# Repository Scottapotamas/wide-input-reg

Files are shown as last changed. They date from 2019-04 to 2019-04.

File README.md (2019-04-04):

# Wide input (HV) DC Step-down Regulator
This is a smaller board that follows the successful design used on the zaphod-bot delta robot, which used 75VDC input and 12V output, tested at 4A load with 96% efficiency.

This board is intended as a medium scale (~50-100W) standalone version for use with 12S lipo systems (48Vish) and similar high voltage supplies, as its hard to get a high input voltage regulator from Pololu etc.

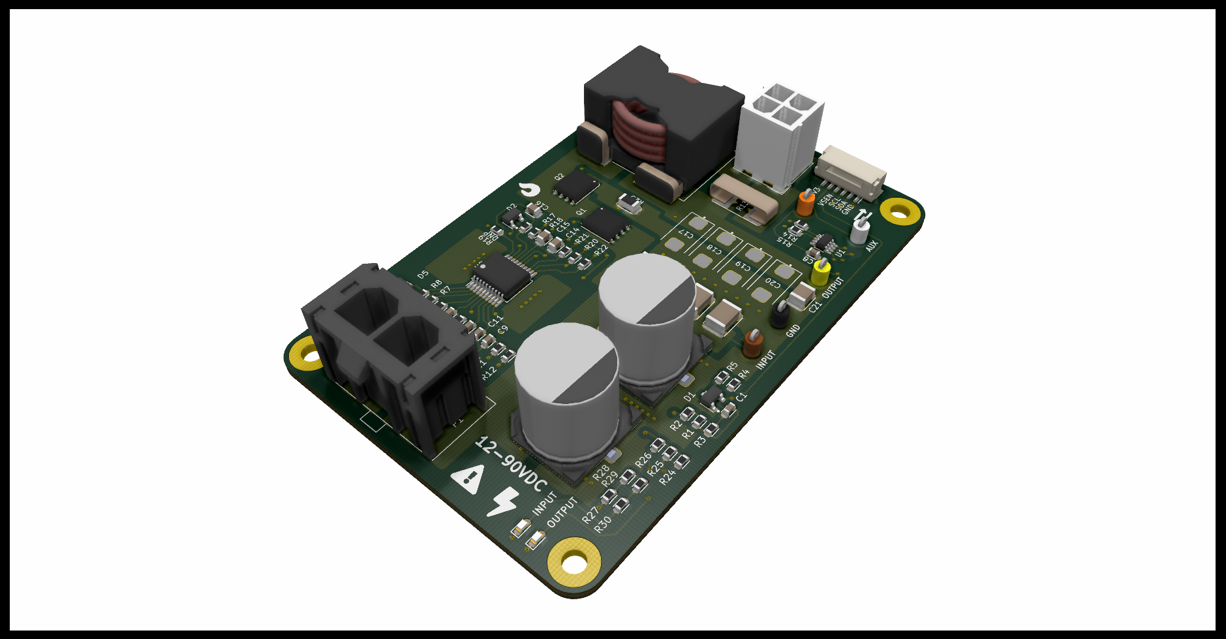
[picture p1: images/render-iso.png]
isometric render view of pcb


## Design Notes

### Regulator

Uses a TI regulator, and a reasonably chunky inductor/filtering stage to ensure stability and efficiency. This design isn't designed for low cost, as I don't forsee low runs, and high voltage systems which require a board like this aren't typically cheap to begin with.

While the regulator and most parts are capable of 100VDC inputs, I've intended the maximum input voltage to be around 80VDC, and I'd expect the design to be used for 5, 12, or 24V outputs (though other outputs are achievable with some component changes).

### Sensing and feedback

Onboard output voltage and current sensing is achieved with the INA219 I2C sense IC, which allows the output voltage and current to be accurately reported to a host microcontroller.

Regulator provides some minimal status indication with 2 leds mounted near the input connector: 

- Red LED indicates the presence of input voltage, and the 

- Green LED indicates the presence of an output voltage. 

- These LED's are 'dumb' and do not indicate if the input/output voltages are _correct_.

A series of onboard solder link jumpers are used to set the I2C address of the INA219, for systems which use multiple regulator boards for different logic levels.

### Connectors

- Input power connection with Molex Sabre 2-pin connector, output with Molex Minifit 4-pin. 

- Data is a JST-GH locking 6-pin connector, which should provide 3.3V, and I2C from the host system. 
  - An (optionally connected) 3.3V analog signal provides input voltage sensing for an ADC, with a 27:1 divider.
  
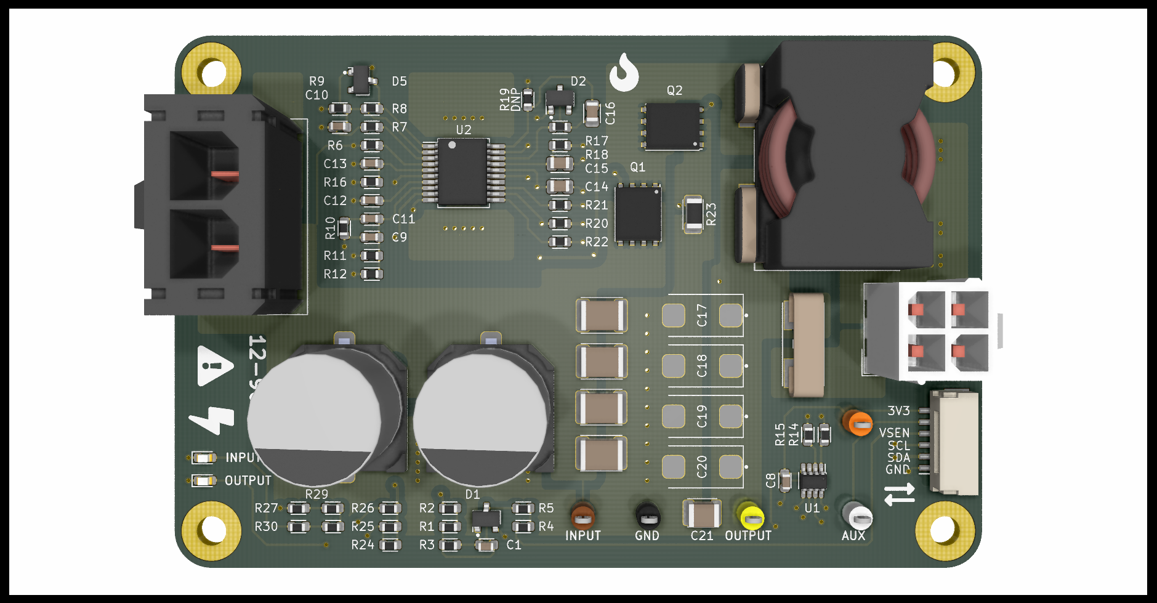
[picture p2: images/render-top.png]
top render view of pcb


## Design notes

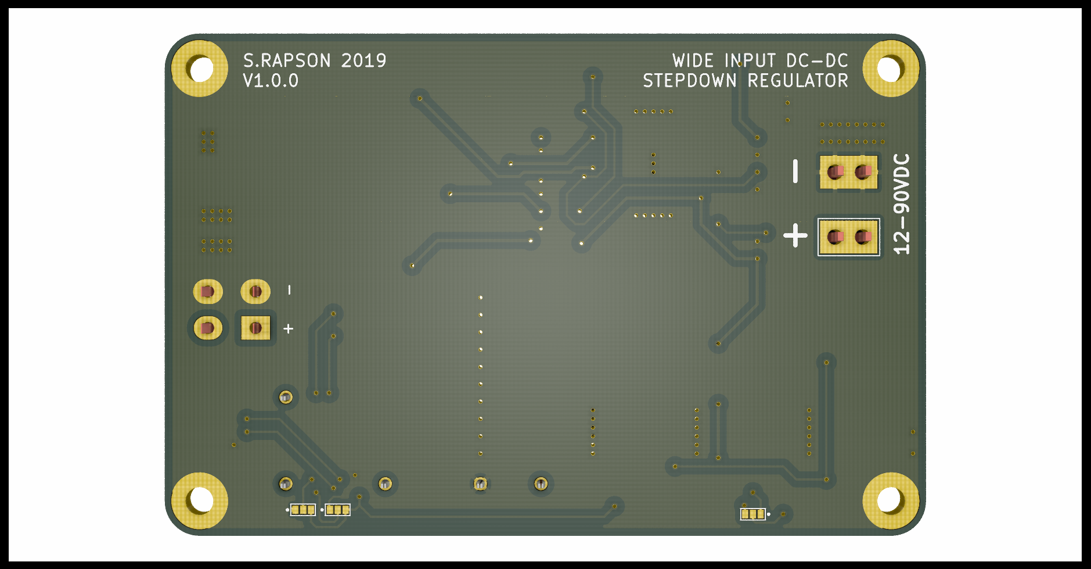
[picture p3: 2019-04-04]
images/render-bottom.png

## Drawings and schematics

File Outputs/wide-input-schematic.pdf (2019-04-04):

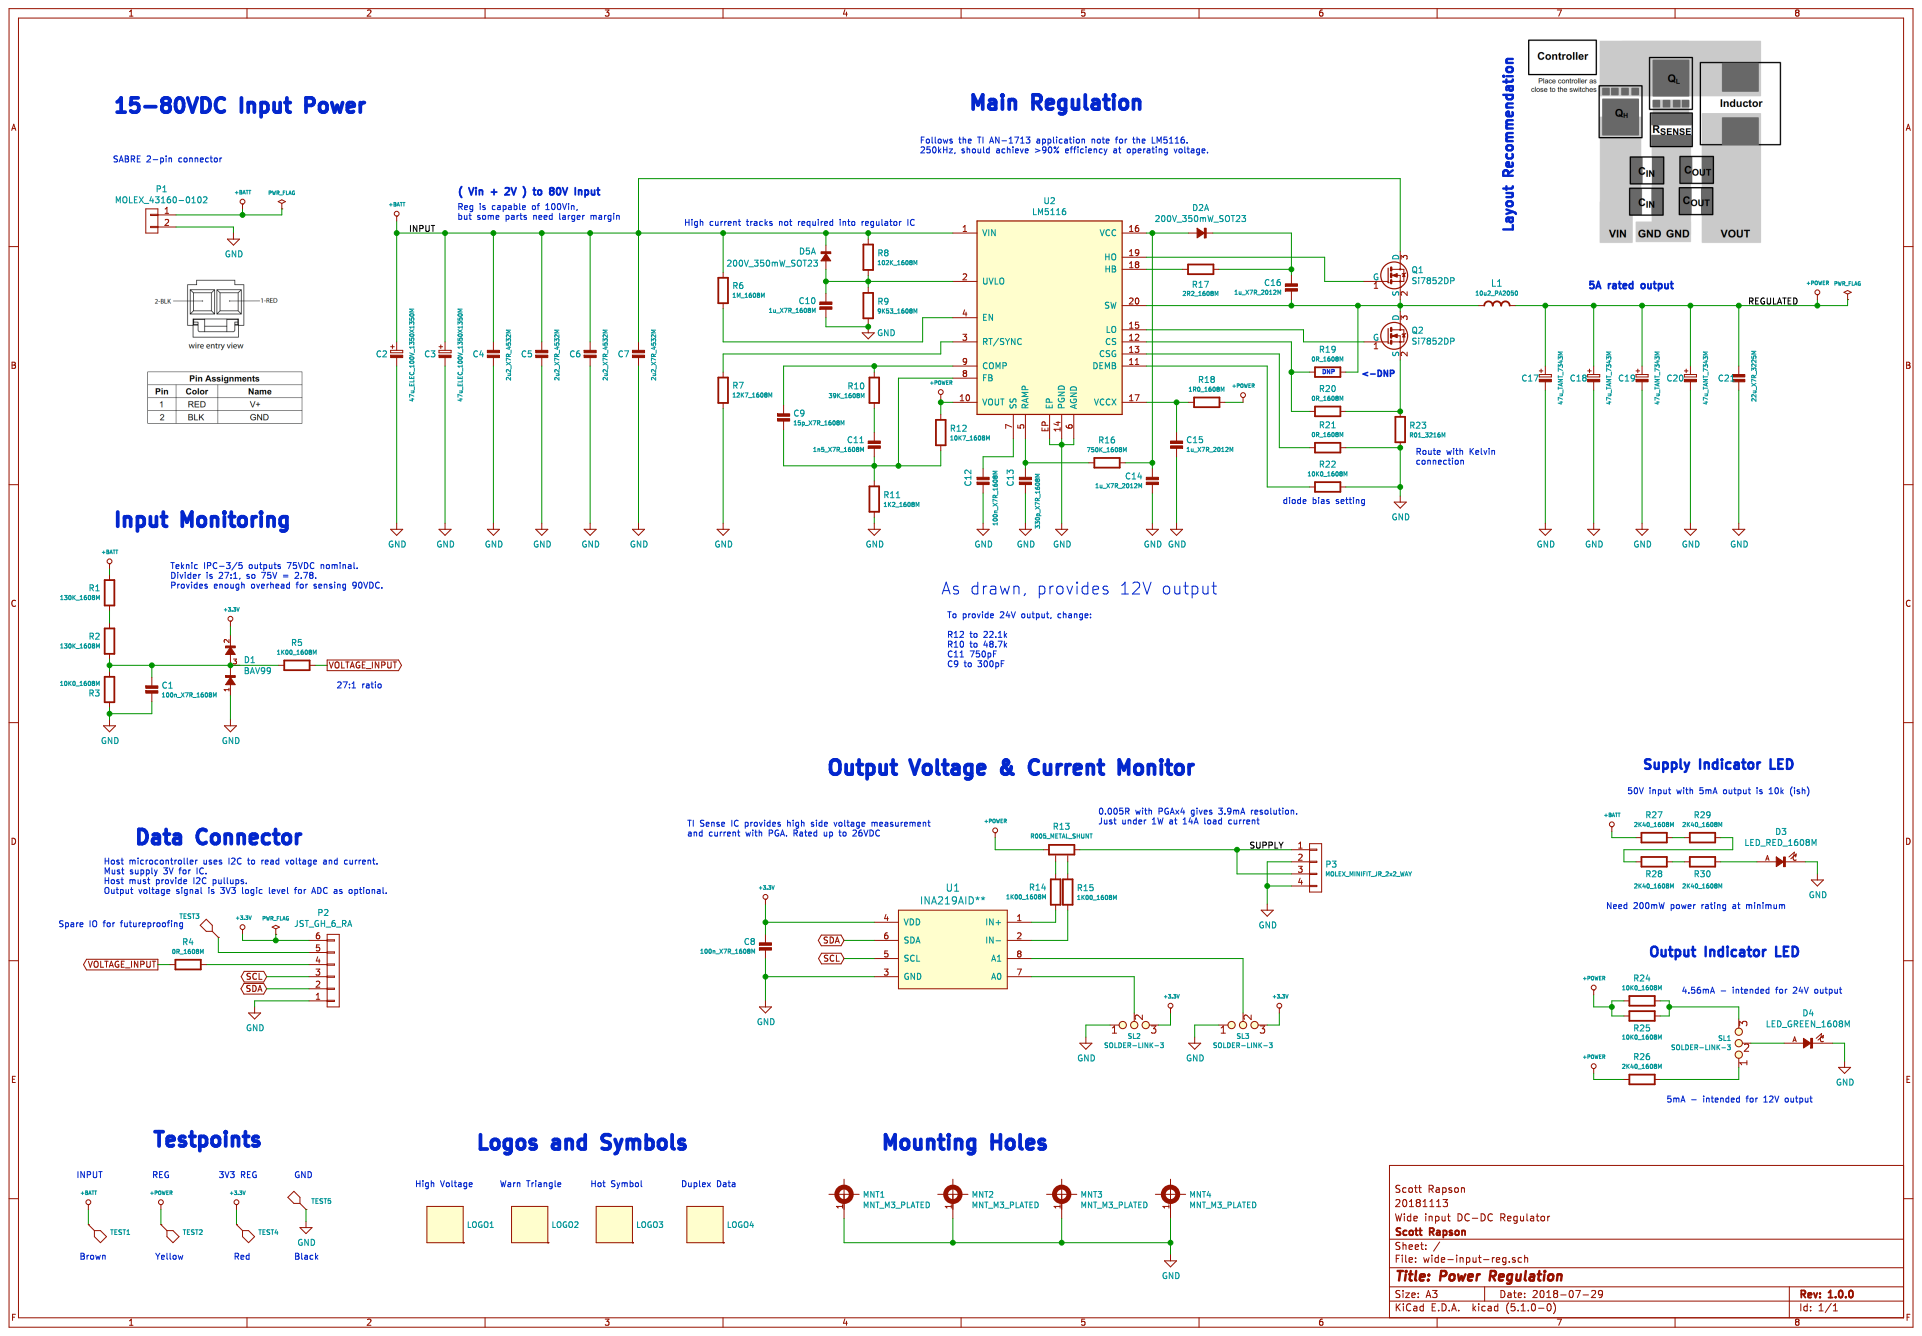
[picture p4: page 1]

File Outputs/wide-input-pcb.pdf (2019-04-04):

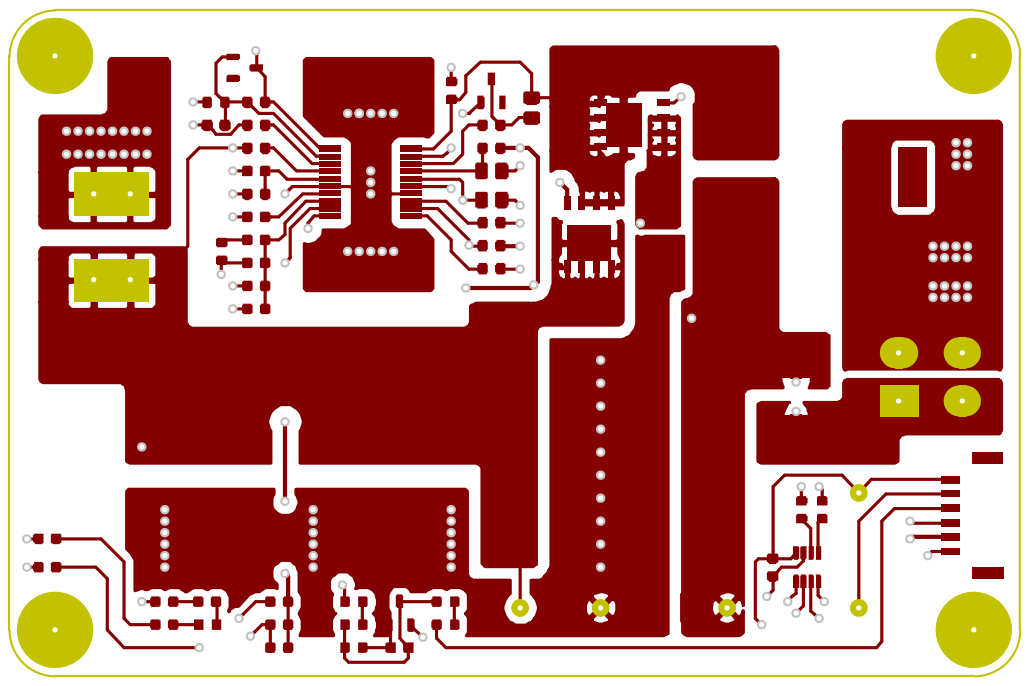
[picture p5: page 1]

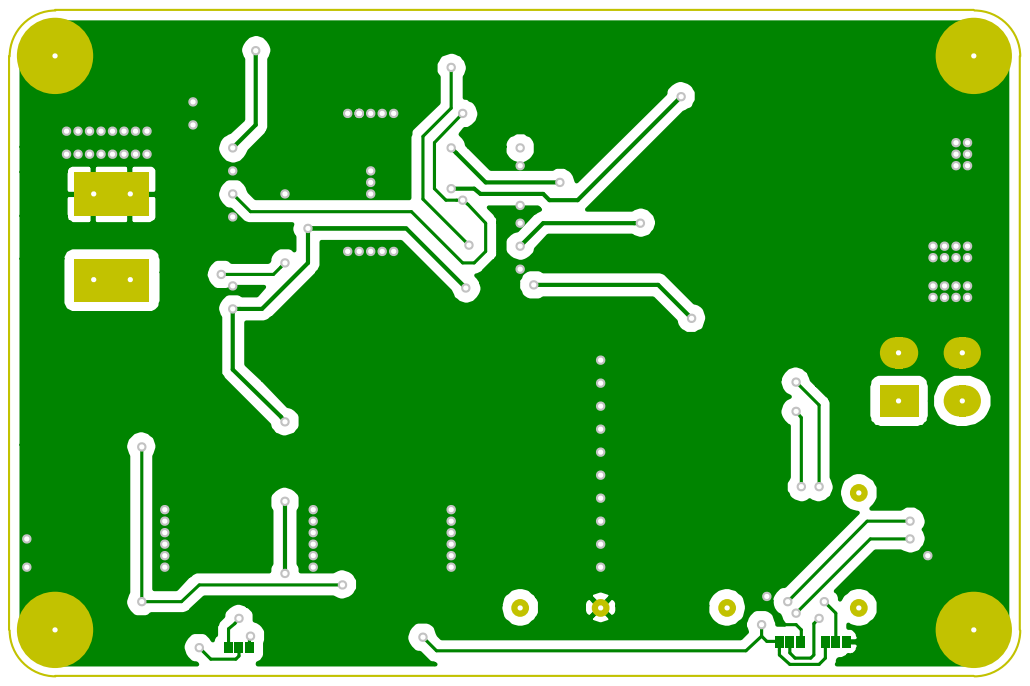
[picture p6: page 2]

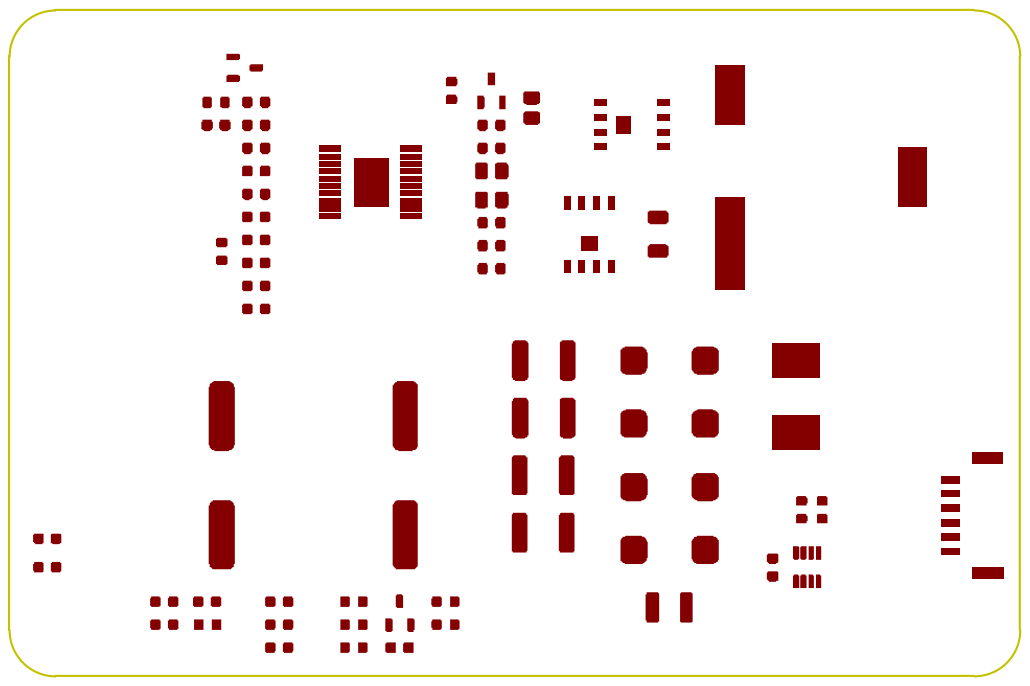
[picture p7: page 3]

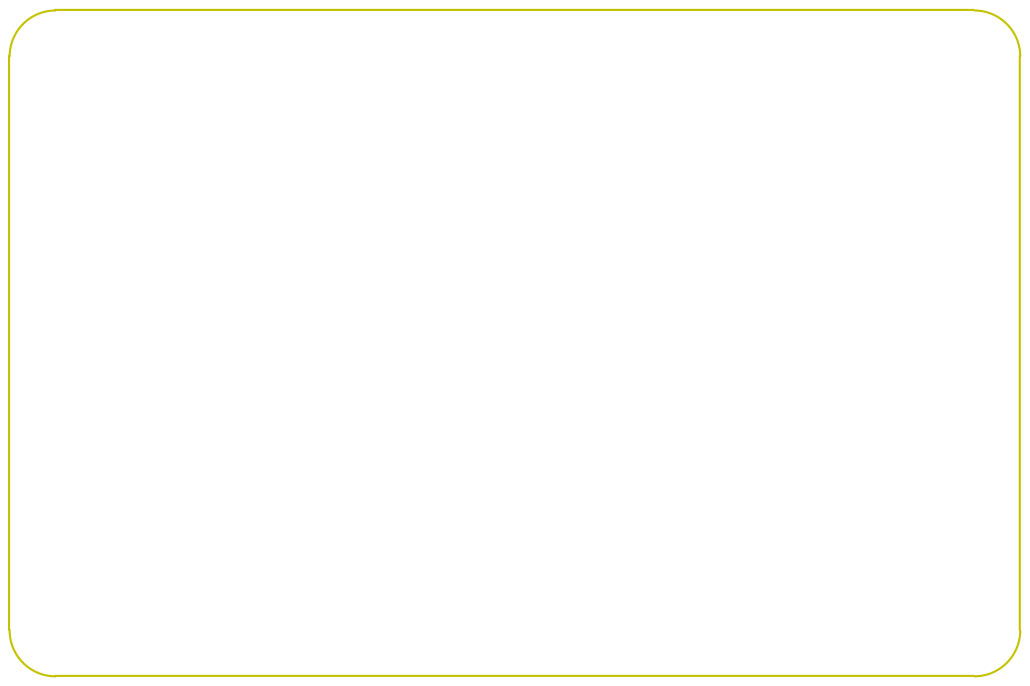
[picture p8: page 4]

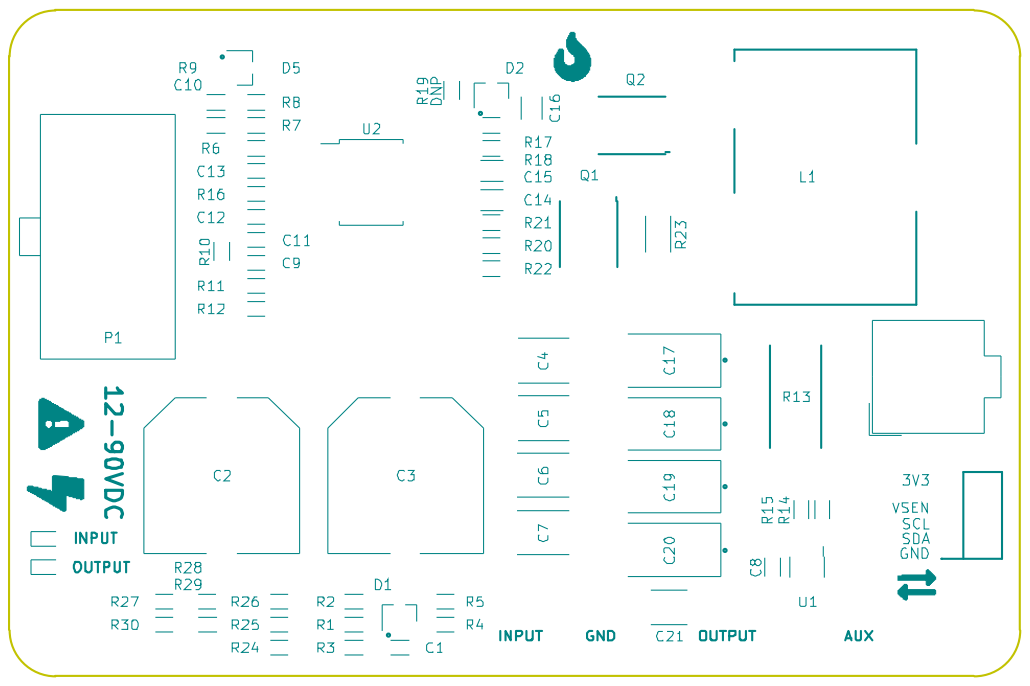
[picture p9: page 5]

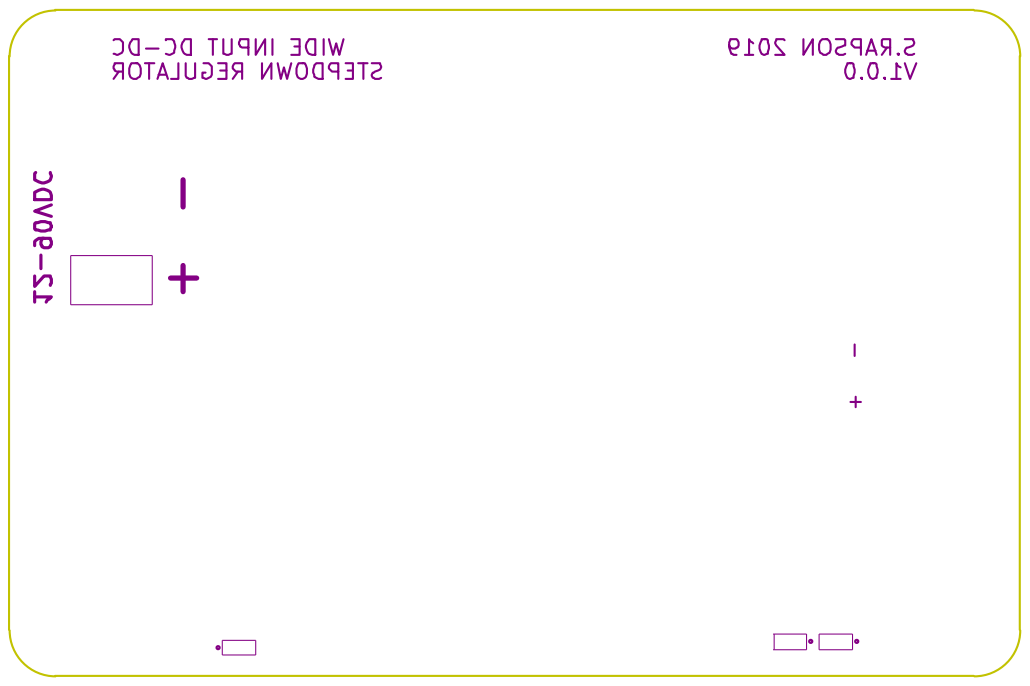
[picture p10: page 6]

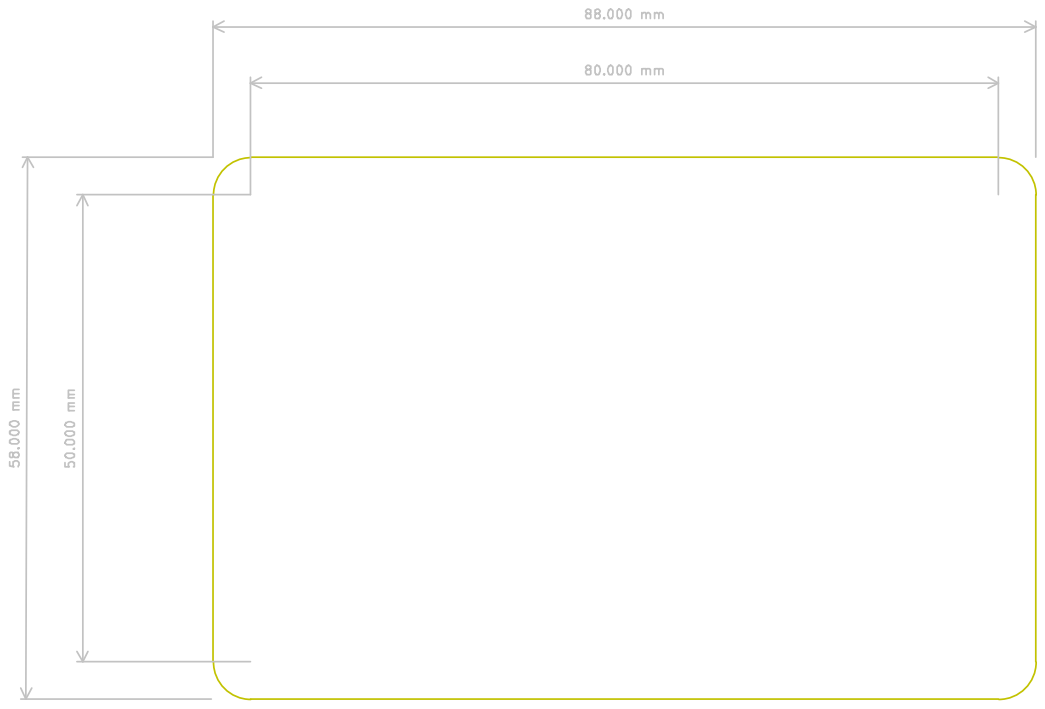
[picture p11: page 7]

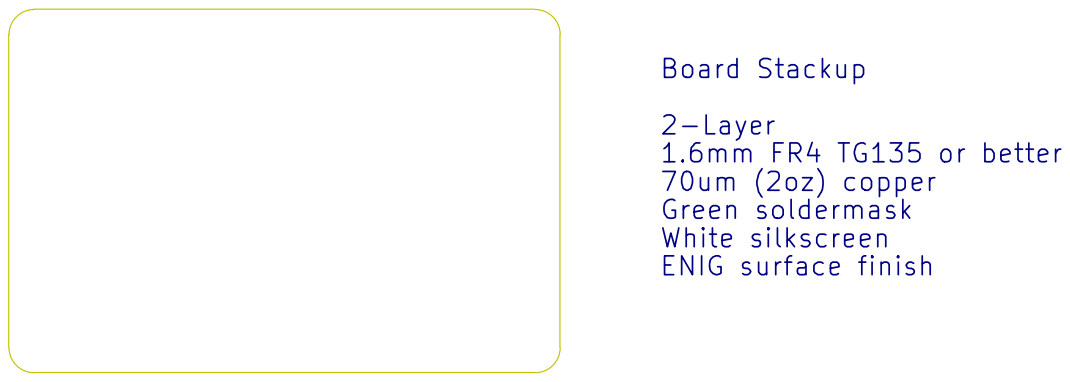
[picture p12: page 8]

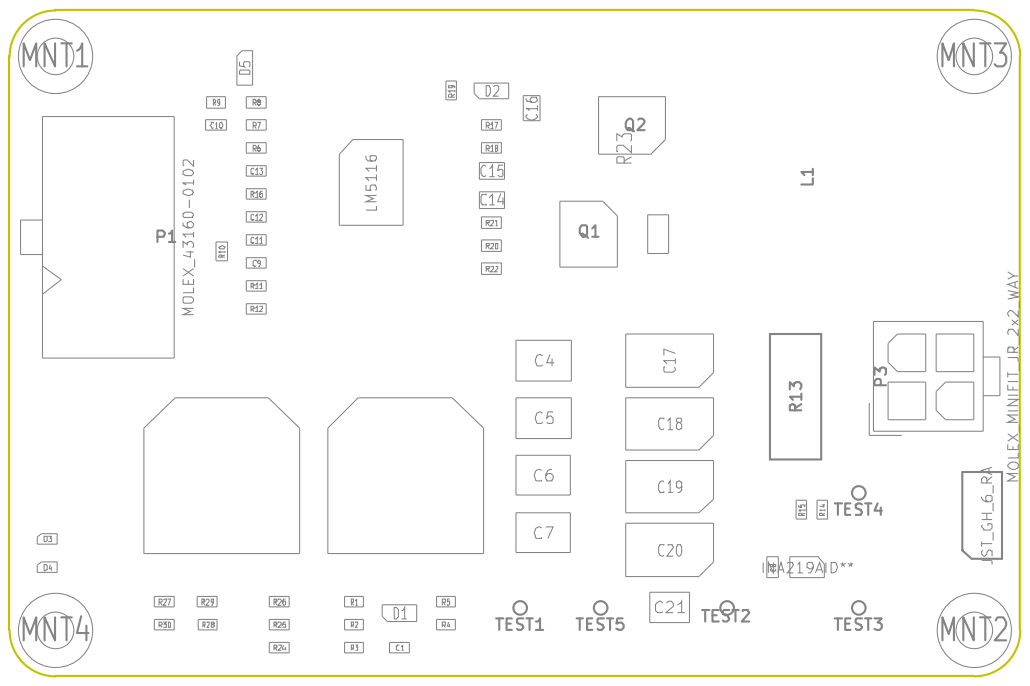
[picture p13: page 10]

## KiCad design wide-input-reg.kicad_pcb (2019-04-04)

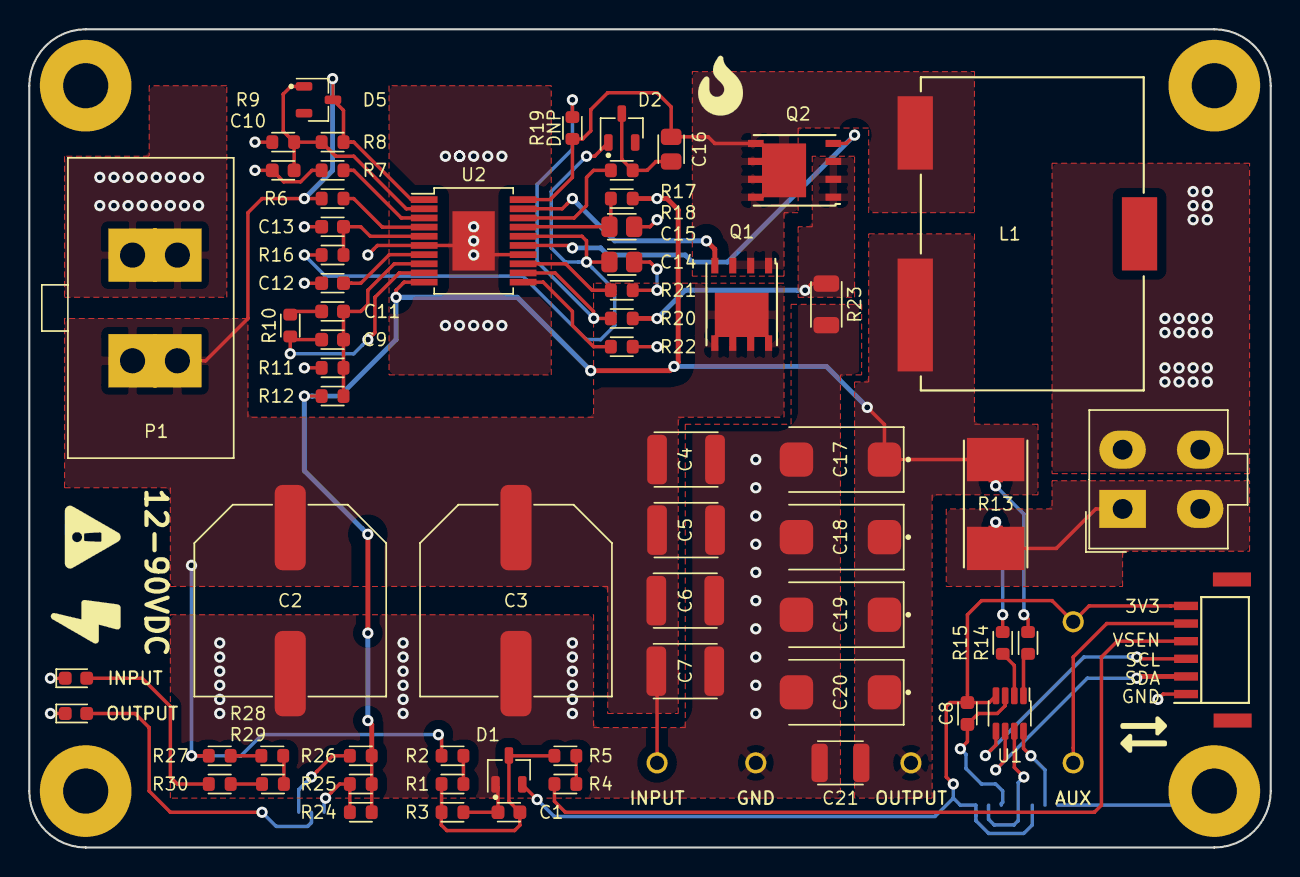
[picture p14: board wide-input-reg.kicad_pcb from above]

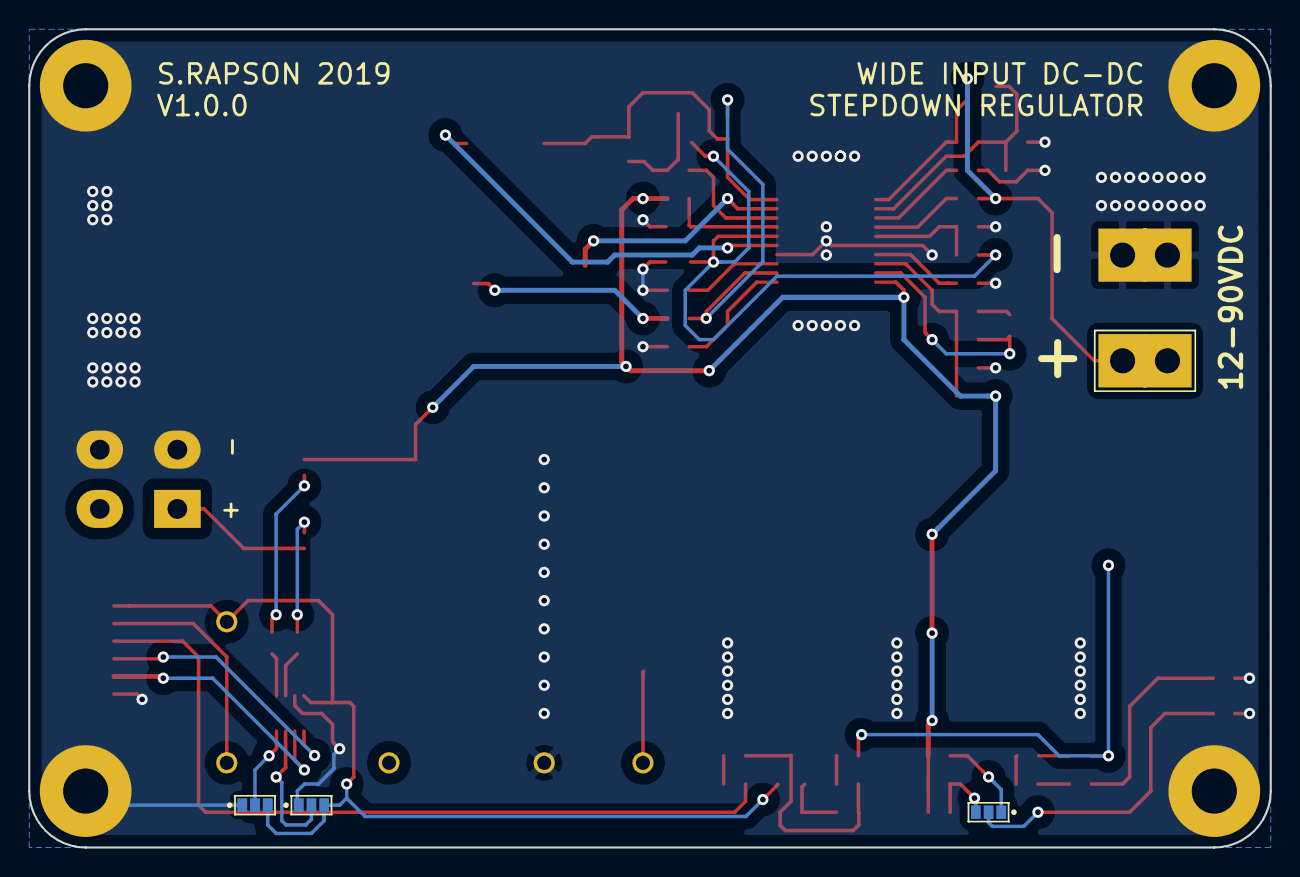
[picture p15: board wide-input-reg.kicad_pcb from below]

Board: 2 copper layers, 88.0 x 58.0 mm, 80 parts (3 on the bottom side), 44 nets.

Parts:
C1, C8, C12: 100n_X7R_1608M; CAPC1608X90N
C2, C3: 47u_ELEC_100V_1350X1350M; CAPAE1350X1350D1490DD450L470N
C4, C5, C6, C7: 2u2_X7R_4532M; CAPC4532X180N
C9: 15p_X7R_1608M; CAPC1608X90N
C10: 1u_X7R_1608M; CAPC1608X90N
C11: 1n5_X7R_1608M; CAPC1608X90N
C13: 330p_X7R_1608M; CAPC1608X90N
C14, C15, C16: 1u_X7R_2012M; CAPC2012X110N
C17, C18, C19, C20: 47u_TANT_7343M; CAPPM7343X310N
C21: 22u_X7R_3225M; CAPC3225X170N
D1: BAV99; SOT95P240X110-3L16N
D2, D5: 200V_350mW_SOT23; SOT95P240X110-3L16N
D3: LED_RED_1608M; LEDC1608X80L40N
D4: LED_GREEN_1608M; LEDC1608X80L40N
L1: 10u2_PA2050; PULSE_PA2050
LOGO1: LOGO; BOLT_LOGO_310X490
LOGO2: LOGO; WARN_TRIANGLE_LOGO440X400
LOGO3: LOGO; FIRE_LOGO_320X420
LOGO4: LOGO; DUPLEX_LOGO330X260
MNT1, MNT2, MNT3, MNT4: MNT_M3_PLATED; MTGP650H330
P1: MOLEX_43160-0102; Molex_Sabre_43160-0102_VERT
P2: JST_GH_6_RA; SM06B-GHS-TB
P3: MOLEX_MINIFIT_JR_2x2_WAY; Molex_Mini-Fit_Jr_5566-04A_2x02_P4.20mm_Vertical
Q1, Q2: Si7852DP; SON127P490X575X90-9T313X381M
R1, R2: 130K_1608M; RESC1608X50N
R3, R22, R24, R25: 10K0_1608M; RESC1608X50N
R4, R19, R20, R21: 0R_1608M; RESC1608X50N
R5, R14, R15: 1K00_1608M; RESC1608X50N
R6: 1M_1608M; RESC1608X50N
R7: 12K7_1608M; RESC1608X50N
R8: 102K_1608M; RESC1608X50N
R9: 9K53_1608M; RESC1608X50N
R10: 39K_1608M; RESC1608X50N
R11: 1K2_1608M; RESC1608X50N
R12: 10K7_1608M; RESC1608X50N
R13: R005_METAL_SHUNT; OARS1-R005FI
R16: 750K_1608M; RESC1608X50N
R17: 2R2_1608M; RESC1608X50N
R18: 1R0_1608M; RESC1608X50N
R23: R01_3216M; RESC3216X140N
R26, R27, R28, R29, R30: 2K40_1608M; RESC1608X50N
SL1, SL2, SL3: SOLDER-LINK-3; SJ1608-3N
TEST1: CLIP_HOOK_BROWN; KEYSTONE_5115
TEST2: CLIP_HOOK_YELLOW; KEYSTONE_5004
TEST3: CLIP_HOOK_WHITE; KEYSTONE_5002
TEST4: CLIP_HOOK_ORANGE; KEYSTONE_5003
TEST5: CLIP_HOOK_BLACK; KEYSTONE_5001
U1: INA219AID**; SOT23-8P65_280X145L45X30N
U2: LM5116; SOP21P65_720X780X200L75X30N

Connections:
+3.3V: C8.2, D1.2, P2.6, SL2.3, SL3.3, TEST4.1, U1.4
+BATT: C2.1, C3.1, C4.1, C5.1, C6.1, C7.1, D5.3, P1.1, Q1.3, R1.2, R6.2, R8.1, R27.2, TEST1.1, U2.1
+POWER: C17.1, C18.1, C19.1, C20.1, C21.1, L1.2, R12.1, R13.1, R18.1, R24.2, R25.2, R26.2, TEST2.1, U2.10
/SUPPLY: P3.1, P3.3, R13.2
GND: C1.2, C2.2, C3.2, C4.2, C5.2, C6.2, C7.2, C8.1, C10.1, C12.2, C13.2, C14.1, C15.1, C17.2, C18.2, C19.2, C20.2, C21.2, D1.1, D3.C, D4.C, MNT1.1, MNT2.1, MNT3.1, MNT4.1, P1.2, P2.1, P3.2, P3.4, R3.1, R7.1, R9.2, R11.2, R21.1, R22.1, R23.2, SL2.1, SL3.1, TEST5.1, U1.3, U2.6, U2.14, U2.EP
unnamed: C1.1, D1.3, R2.1, R3.2, R5.2
unnamed: C9.1, R10.1, U2.9
unnamed: C10.2, D5.1, R8.2, R9.1, U2.2
unnamed: C9.2, C11.1, R11.1, R12.2, U2.8
unnamed: C11.2, R10.2
unnamed: C12.1, U2.7
unnamed: C13.1, R16.2, U2.5
unnamed: C14.2, D2.1, R16.1, U2.16
unnamed: C15.2, R18.2, U2.17
unnamed: C16.1, L1.1, Q1.2, Q2.3, R19.1, U2.20
unnamed: C16.2, D2.3, R17.2
unnamed: D3.A, R30.1
unnamed: D4.A, SL1.2
unnamed: P2.4, R4.1
unnamed: P2.5, TEST3.1
unnamed: Q1.1, U2.19
unnamed: Q2.1, U2.15
unnamed: Q2.2, R20.1, R23.1
unnamed: R1.1, R2.2
unnamed: R6.1, U2.4
unnamed: R7.2, U2.3
unnamed: R13.3, R14.2
unnamed: R13.4, R15.1
unnamed: R14.1, U1.1
unnamed: R15.2, U1.2
unnamed: R17.1, U2.18
unnamed: R19.2, R20.2, U2.12
unnamed: R21.2, U2.13
unnamed: R22.2, U2.11
unnamed: R24.1, R25.1, SL1.3
unnamed: R26.1, SL1.1
unnamed: R27.1, R29.2
unnamed: R28.1, R30.2
unnamed: R28.2, R29.1
unnamed: SL2.2, U1.7
unnamed: SL3.2, U1.8
SCL: P2.3, U1.5
SDA: P2.2, U1.6
VOLTAGE_INPUT: R4.2, R5.1

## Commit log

2018-11-13 Moved current project files into repo.
    Schematic base is complete(ish) and some very preliminary parts layout has started.
    [wide-input-reg.kicad_pcb, wide-input-reg.sch]
2018-11-13 Minor readme formatting changes
    [wide-input-reg.kicad_pcb]
2018-11-23 Parts placement
    [wide-input-reg.kicad_pcb, wide-input-reg.sch]
2018-11-23 Routing and copper pours
    [wide-input-reg.kicad_pcb]
2018-11-23 Routing, Silkscreen, pour tweaks, etc
    Generally progressing towards completion
    [wide-input-reg.kicad_pcb]
2019-04-04 Silkscreen text, finished remaining tracks, etc
    Ready for fab
    [wide-input-reg.kicad_pcb]
2019-04-04 Adds gerbers and PDF exports
    [wide-input-reg-B_Cu.gbl, wide-input-reg-B_Mask.gbs, wide-input-reg-B_Paste.gbp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]
2019-04-04 Adds rendered views of PCB
